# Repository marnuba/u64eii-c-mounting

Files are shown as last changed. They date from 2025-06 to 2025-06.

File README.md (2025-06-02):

# Ultimate 64 Elite II mounting brackets for the original C64c case.

Can be printed without support when laying on the side. I used PLA which appears to work just fine.

It is a snug fit, so to install, first put in the left bracket, then the board, then slide in the right bracket.

I used double sided tape to fix the brackets in addition to the screw. However, this might be not necessary at all.

# Pictures
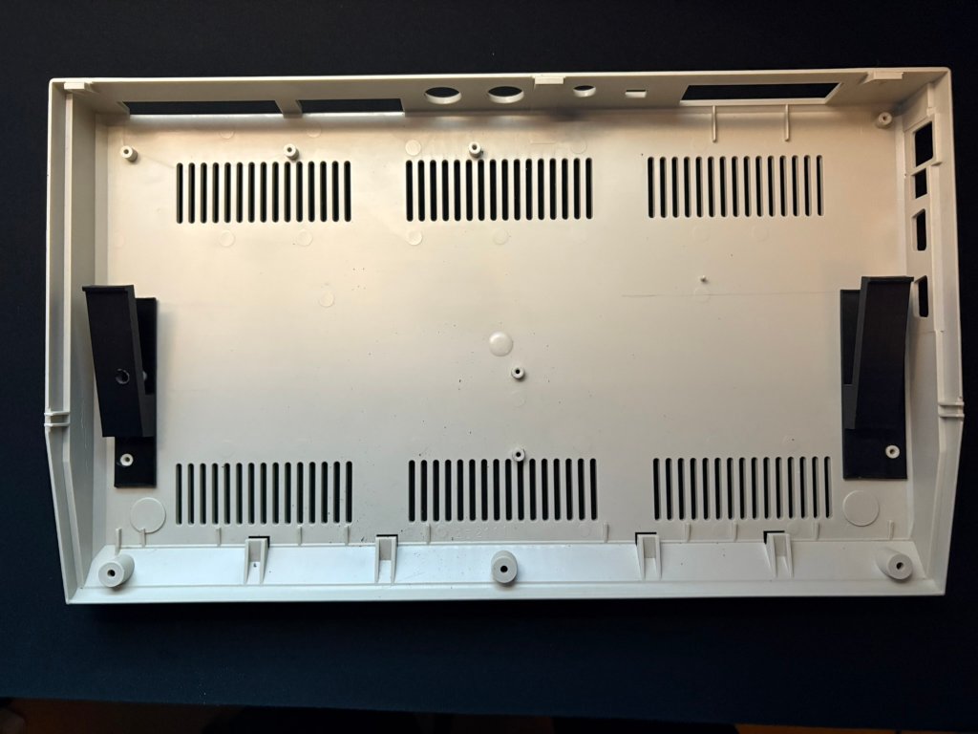
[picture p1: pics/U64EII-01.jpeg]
Topview both brackets

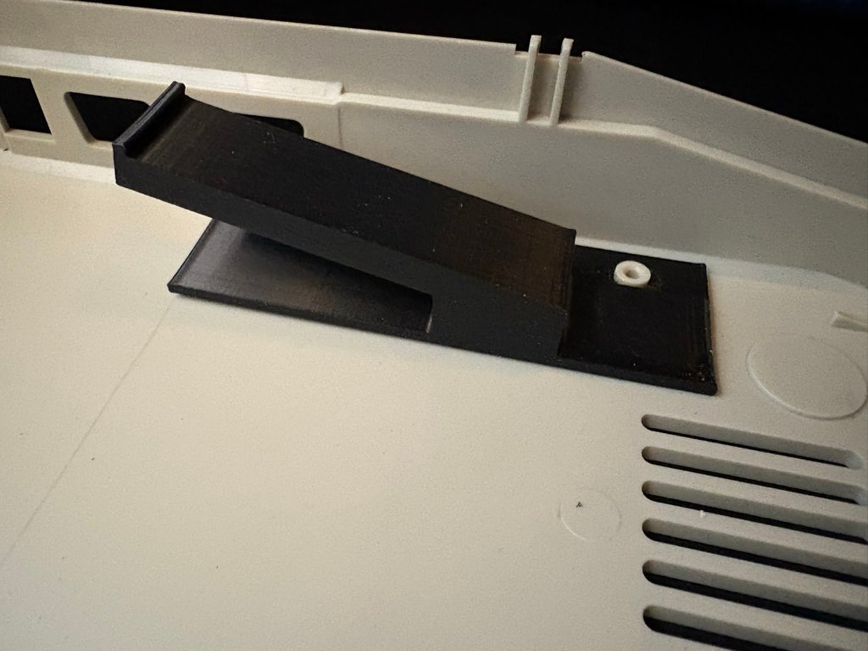
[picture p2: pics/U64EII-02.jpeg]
Right bracket

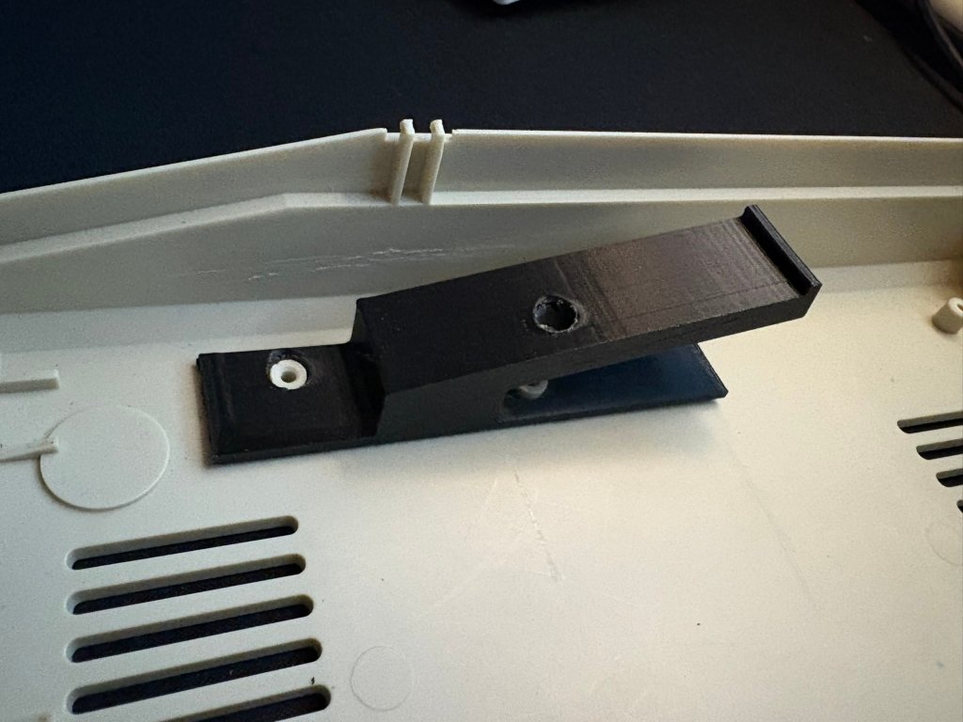
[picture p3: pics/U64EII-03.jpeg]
Left bracket

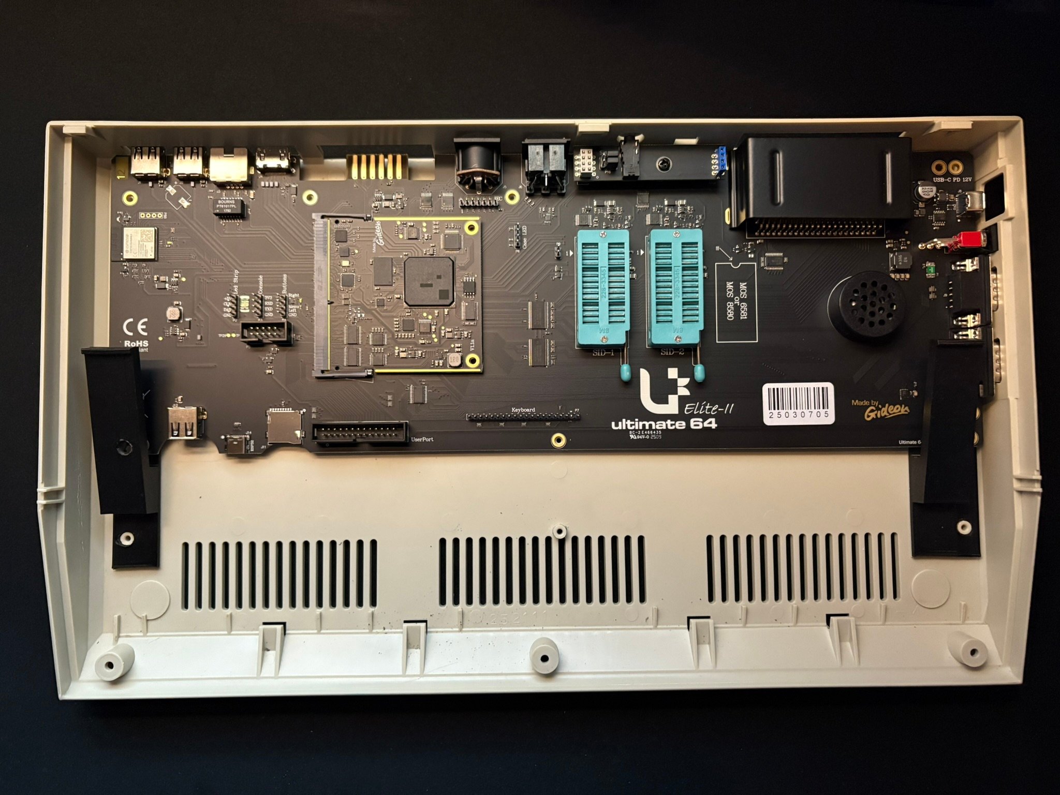
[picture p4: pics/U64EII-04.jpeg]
Board fitted

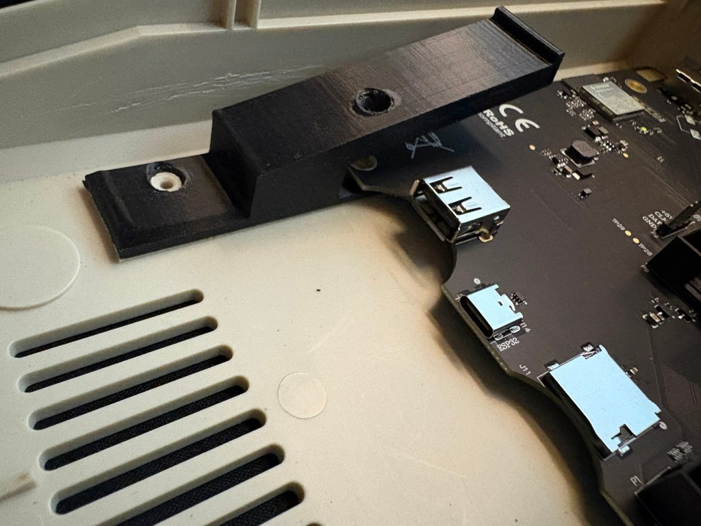
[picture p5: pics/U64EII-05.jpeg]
Left bracket with board inserted

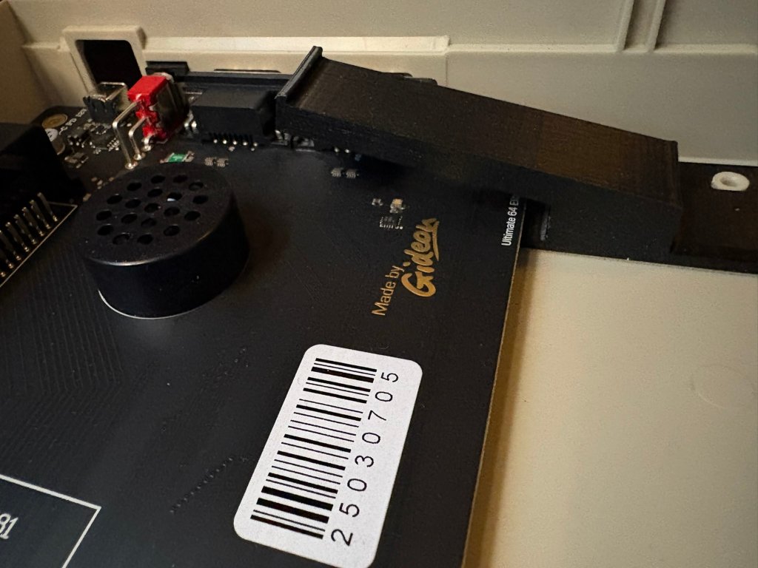
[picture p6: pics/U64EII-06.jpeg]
Right bracket with board inserted

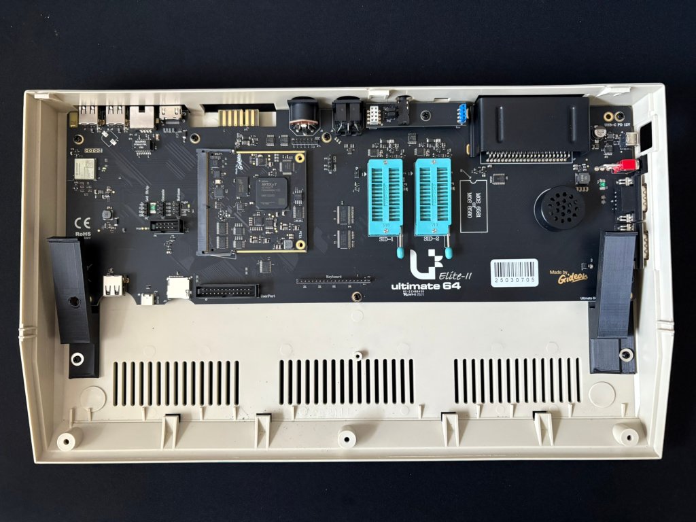
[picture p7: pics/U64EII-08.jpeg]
Insert screws

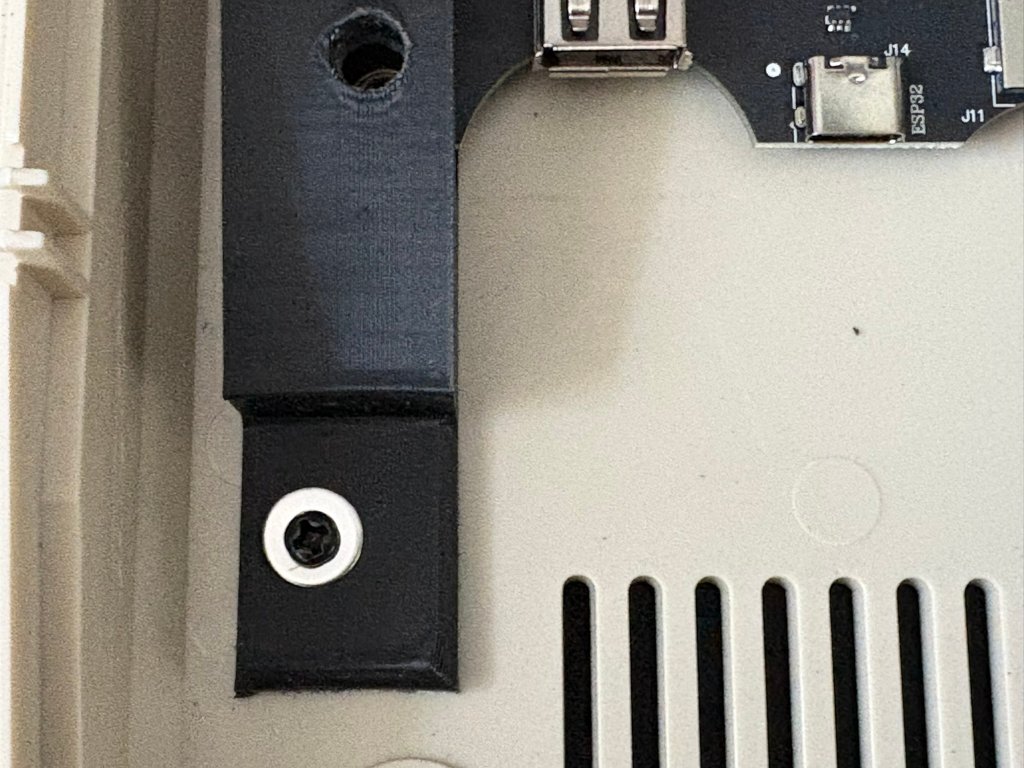
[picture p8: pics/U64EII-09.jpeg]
Left screw closeup

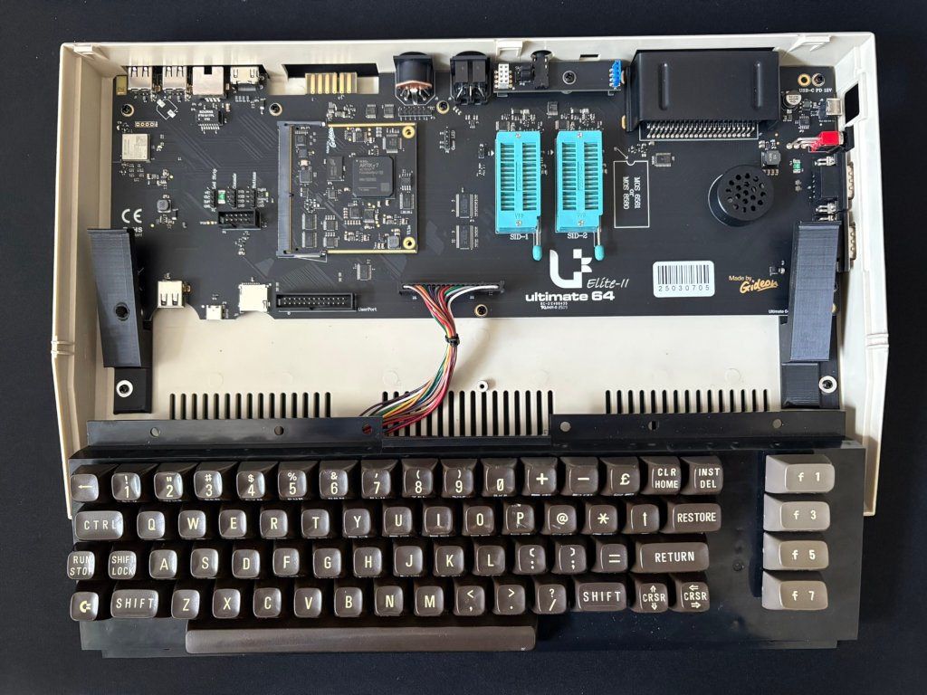
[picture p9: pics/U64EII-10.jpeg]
Attach keyboard

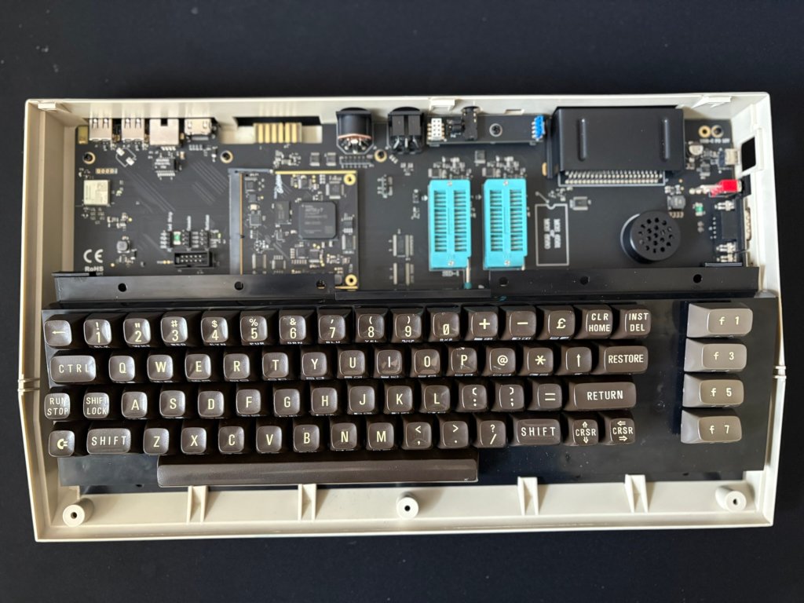
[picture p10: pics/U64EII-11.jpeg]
Place keyboard

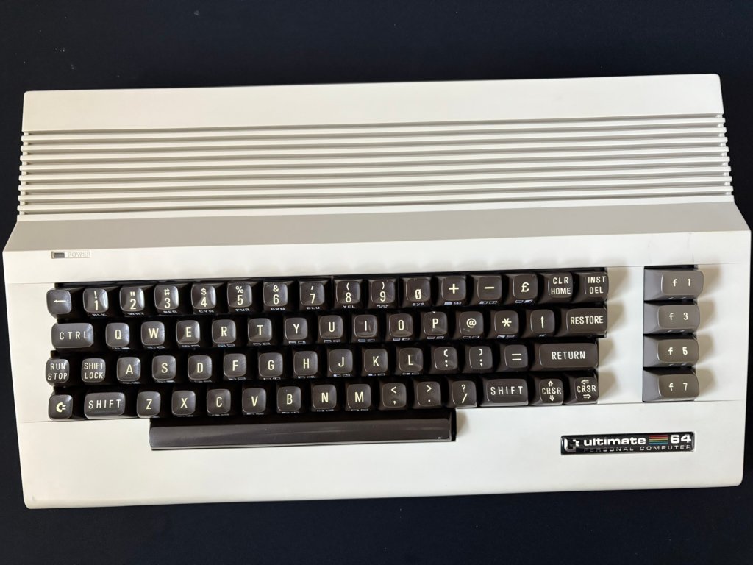
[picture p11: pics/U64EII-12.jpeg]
Close case


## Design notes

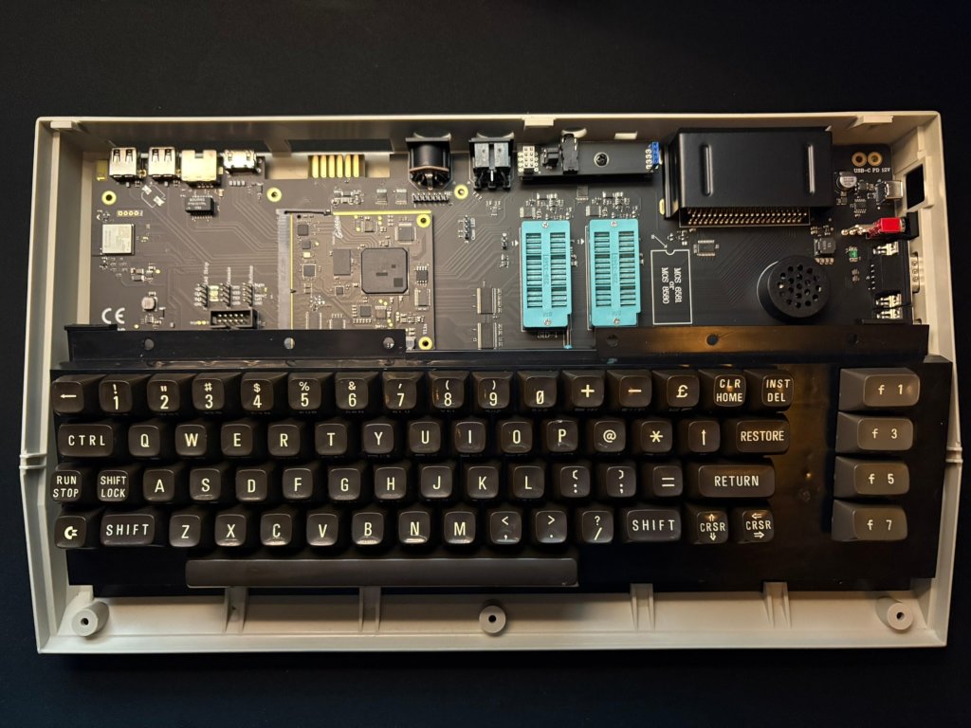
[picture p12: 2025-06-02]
pics/U64EII-07.jpeg

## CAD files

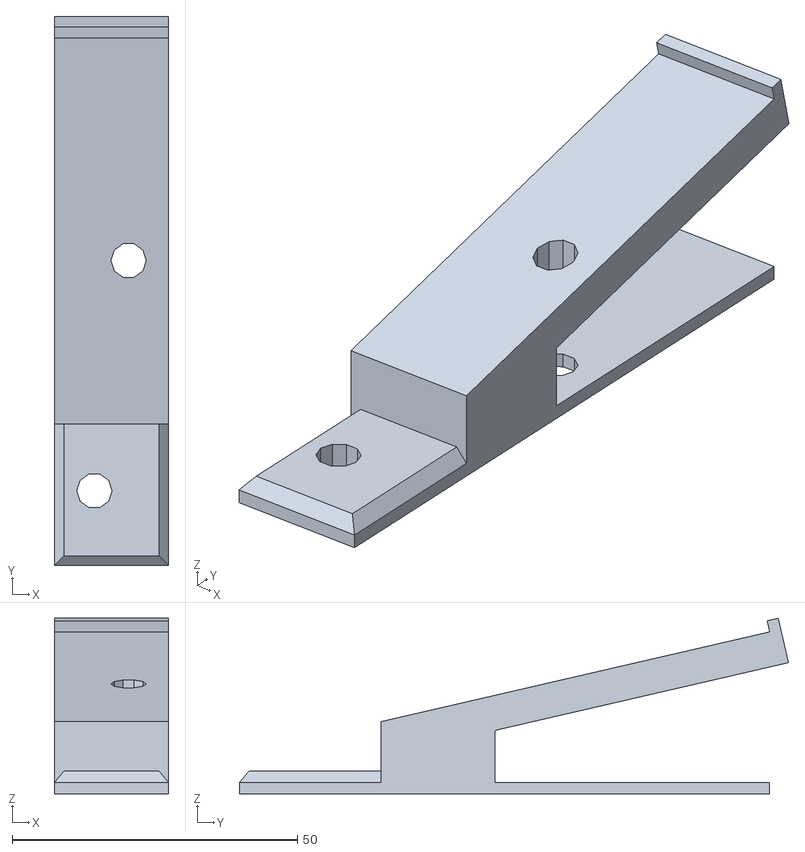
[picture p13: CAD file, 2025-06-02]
stl/U64_bracket_left.stl
20.0 x 96.3 x 30.8

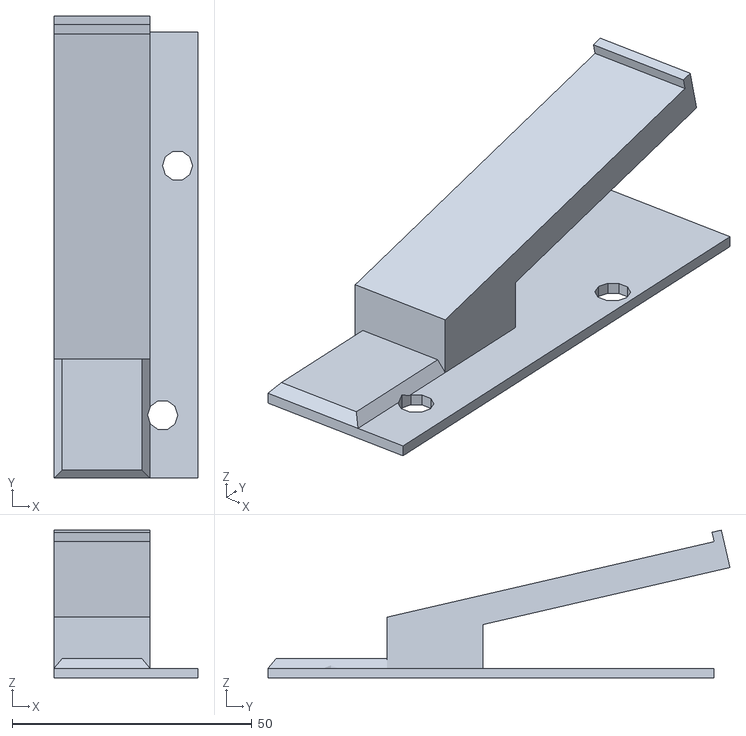
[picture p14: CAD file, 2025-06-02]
stl/U64_bracket_right.stl
30.0 x 96.3 x 30.8

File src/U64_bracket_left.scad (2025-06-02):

include <BOSL2/std.scad>;

width = 20;
rest_len = 70; // how long the part is the keyboard rest on
rest_thickness = 6;

kb_len = 126.25;  // the length (actually depth) of the keyb
kb_angle = 13;  // un degree!

kb_ground_len = kb_len * cos(kb_angle);

base_start_abs = 30;
base_len = kb_ground_len - base_start_abs;
base_thickness = 2;

screwpod_height = 4;
screwpod_dia = 6.3;
screwpod_well_dia = 8;

rest_elevation = (kb_len - rest_len) * sin(kb_angle);
rest_start_abs = (kb_len - rest_len) * cos(kb_angle);

rest_start = rest_start_abs - base_start_abs;

module Rest() {
    edgeheight = 2;
    edgewidth = 2;
    restsize = [width, rest_len, rest_thickness];
    edgesize = [restsize.x, edgewidth, restsize.z+edgeheight];
       
    cube(restsize);
    back(restsize.y) cube(edgesize);
}

module Base(basewidth=width) {
    cube([basewidth, base_len, 2]);   
}

module Arm() {
    echo(rest_elevation);
    cube([width, 20, rest_elevation]);
}

module ArmRest() {
    Arm();
    
    fwd(base_start_abs+rest_start)
    xrot(kb_angle) back(kb_len - rest_len)
    down(rest_thickness)
    Rest();
}

module Screwpod() {
    sp_len = rest_start;
     right(width/2) back(sp_len/2) up(2) prismoid(size1=[width, sp_len], h=2, xang=[50,50], yang=[50,90]);
}

module Structure(basewidth) {
    Base(basewidth);
    back(rest_start) ArmRest();
    Screwpod();
}


module Screwhole(x, y) {
    down(0.01) right(x) back(y) cylinder(r=screwpod_dia/2, h=40.02);
}


module Left_Holder() {
    difference() {
        Structure(width);
        Screwhole(7, 13.1);
        Screwhole(13, 13.1+40.4);
    }
}

module Right_Holder() {
    difference() {
        basewidth = width + 10;
        Structure(basewidth);
        Screwhole(basewidth - 10.5 + screwpod_dia/2, 13.1);
        Screwhole(basewidth - 7.4 + screwpod_dia/2, 13.1+52);
    }
}


//Left_Holder();
Right_Holder();
